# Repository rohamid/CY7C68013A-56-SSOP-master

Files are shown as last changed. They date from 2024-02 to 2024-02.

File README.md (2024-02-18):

# CY7C68013A 56 SSOP dev board

# Fix this:
* EEPROM connection's. I made a mistake for EERPOM address connection. Pin no.1 should be connected to EEPROM enable jumper.
* USB connector (if you gonna use usb C, don't do manual soldering. It doesn't really that strong, but if you gonna give it to PCBA I think it will gonna do it. Don't know why)
* Try black tactile button, it feel better

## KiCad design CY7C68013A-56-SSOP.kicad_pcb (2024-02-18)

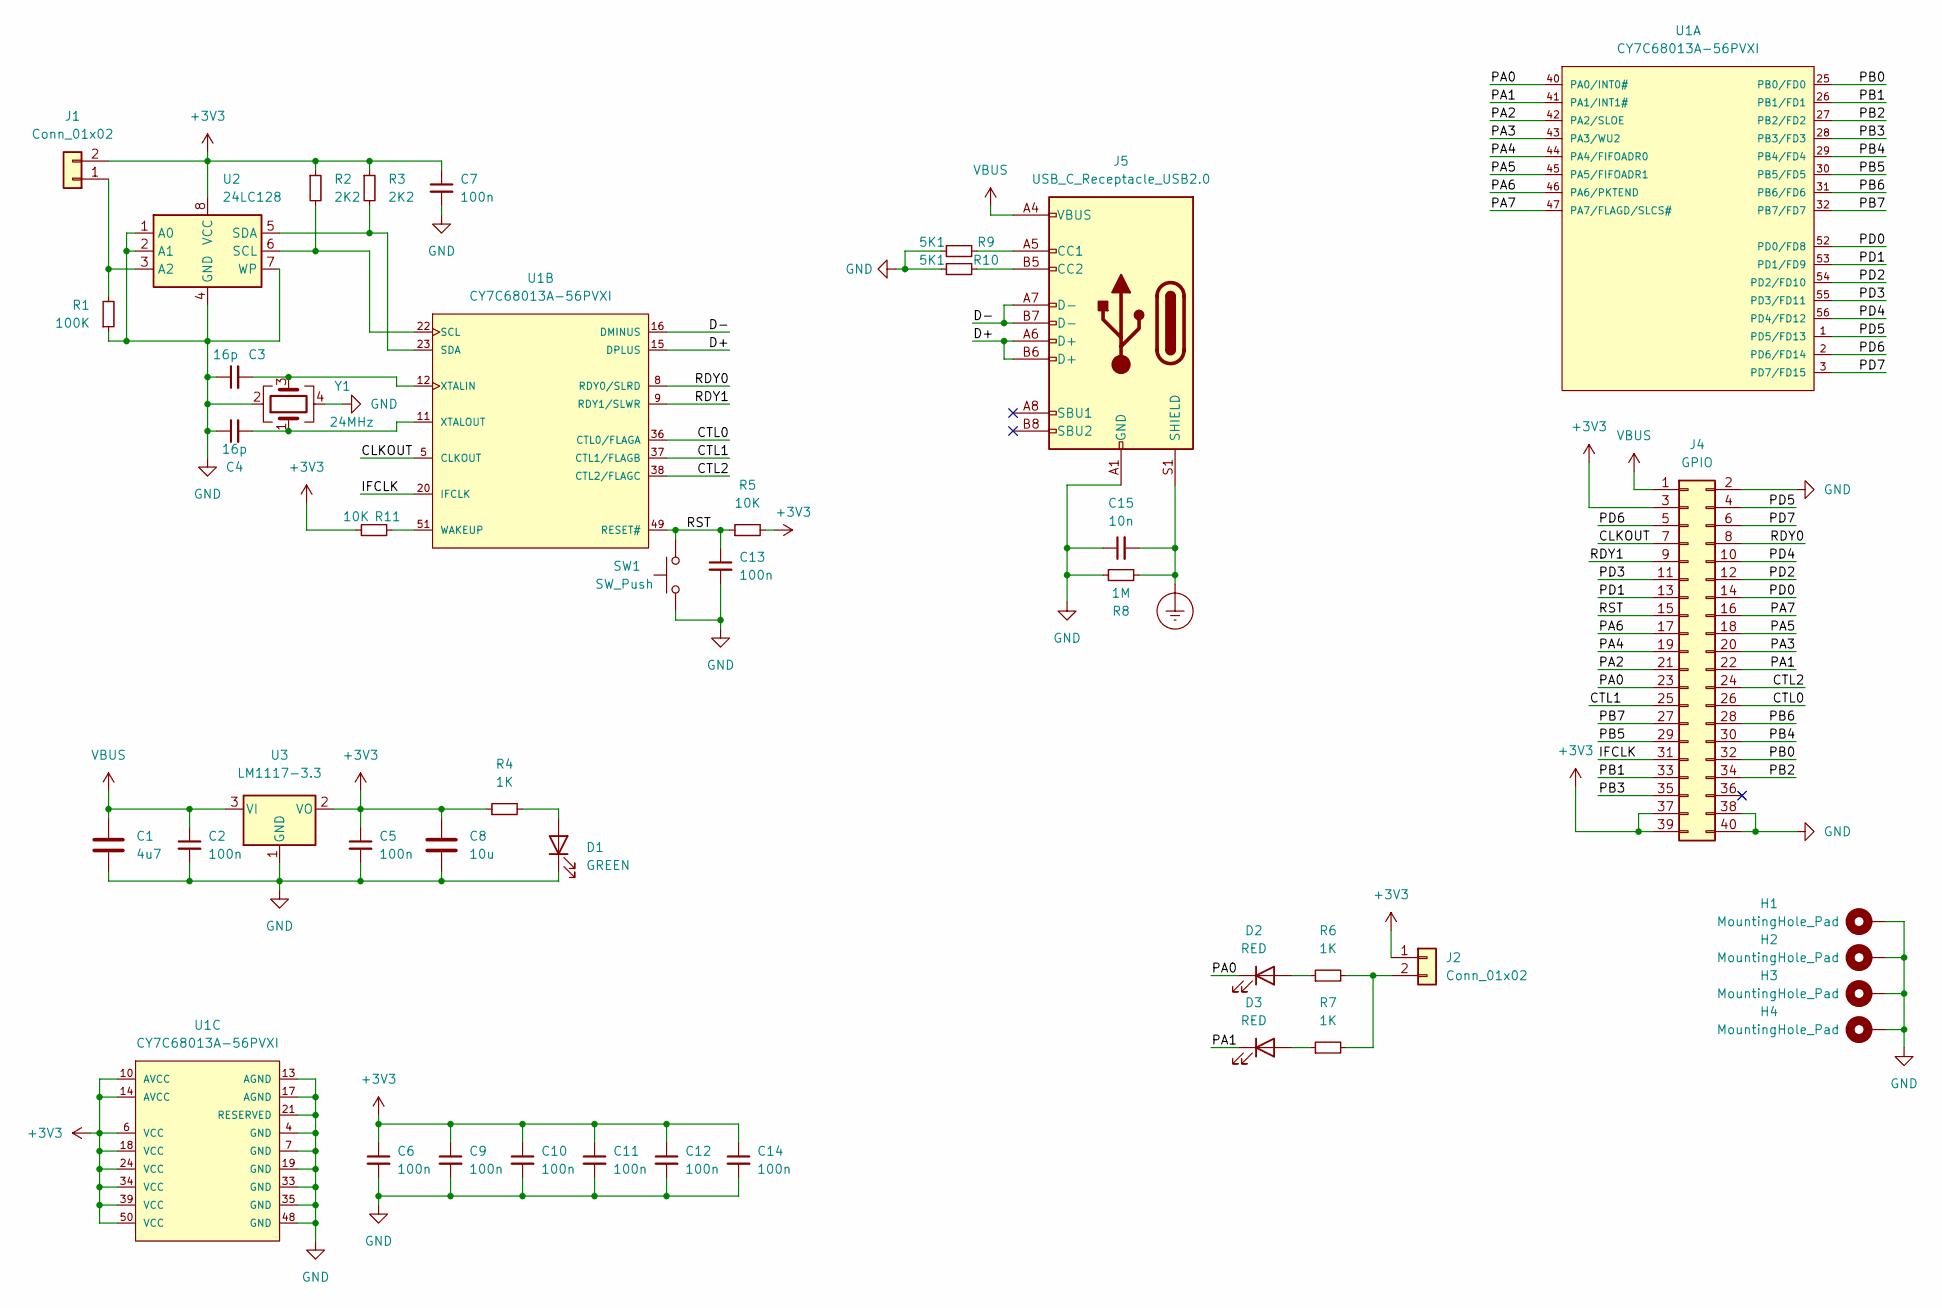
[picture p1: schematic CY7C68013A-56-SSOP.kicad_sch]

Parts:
C1: 4u7; C_0805_2012Metric; LCSC Part Number C1779
C2, C5, C6, C7, C9, C10, C11, C12, C13, C14: 100n; C_0402_1005Metric; LCSC Part Number C307331
C3, C4: 16p; C_0402_1005Metric; LCSC Part Number C1547
C8: 10u; C_0805_2012Metric; LCSC Part Number C15850
C15: 10n; C_0805_2012Metric; LCSC Part Number C106840
D1: GREEN; LED_0805_2012Metric; LCSC Part Number C34499
D2, D3: RED; LED_0805_2012Metric; LCSC Part Number C84256
H1, H2, H3, H4: MountingHole_Pad; MountingHole_3.2mm_M3_Pad_Via
J1, J2: Conn_01x02; PinHeader_1x02_P2.54mm_Vertical
J4: GPIO; PinHeader_2x20_P2.54mm_Horizontal
J5: USB_C_Receptacle_USB2.0; USB_C_Receptacle_G-Switch_GT-USB-7010ASV
R1: 100K; R_0402_1005Metric; LCSC Part Number C25741
R2, R3: 2K2; R_0402_1005Metric; LCSC Part Number C25879
R4, R6, R7: 1K; R_0402_1005Metric; LCSC Part Number C11702
R5: 10K; R_0402_1005Metric; LCSC Part Number C25744
R8: 1M; R_0402_1005Metric; LCSC Part Number C26083
R9, R10: 5K1; R_0402_1005Metric; LCSC Part Number C25744
R11: 10K; R_0402_1005Metric; LCSC Part Number C11702
SW1: SW_Push; SW_Push_1P1T_NO_CK_KMR2; LCSC Part Number C115360
U1: CY7C68013A-56PVXI; SSOP-56_7.5x18.5mm_P0.635mm; LCSC Part Number CY7C68013A-56PVXC
U2: 24LC128; SOIC-8_3.9x4.9mm_P1.27mm; LCSC Part Number C81195
U3: LM1117-3.3; SOT-223-3_TabPin2; LCSC Part Number C6186
Y1: 24MHz; Crystal_SMD_3225-4Pin_3.2x2.5mm; LCSC Part Number C2650460

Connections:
+3V3: C5.1, C6.1, C7.1, C8.1, C9.1, C10.1, C11.1, C12.1, C14.1, J1.2, J2.1, J4.3, J4.37, J4.39, R2.1, R3.1, R4.1, R5.2, R11.1, U1.6 (VCC), U1.10 (AVCC), U1.14 (AVCC), U1.18 (VCC), U1.24 (VCC), U1.34 (VCC), U1.39 (VCC), U1.50 (VCC), U2.8 (VCC), U3.2 (VO); also elsewhere on the board
/CLKOUT: J4.7, U1.5 (CLKOUT)
/CTL0: J4.26, U1.36 (CTL0/FLAGA)
/CTL1: J4.25, U1.37 (CTL1/FLAGB)
/CTL2: J4.24, U1.38 (CTL2/FLAGC)
/D+: J5.A6 (D+), J5.B6 (D+), U1.15 (DPLUS)
/D-: J5.A7 (D-), J5.B7 (D-), U1.16 (DMINUS)
/IFCLK: J4.31, U1.20 (IFCLK)
/PA0: D2.1 (K), J4.23, U1.40 (PA0/INT0#)
/PA1: D3.1 (K), J4.22, U1.41 (PA1/INT1#)
/PA2: J4.21, U1.42 (PA2/SLOE)
/PA3: J4.20, U1.43 (PA3/WU2)
/PA4: J4.19, U1.44 (PA4/FIFOADR0)
/PA5: J4.18, U1.45 (PA5/FIFOADR1)
/PA6: J4.17, U1.46 (PA6/PKTEND)
/PA7: J4.16, U1.47 (PA7/FLAGD/SLCS#)
/PB0: J4.32, U1.25 (PB0/FD0)
/PB1: J4.33, U1.26 (PB1/FD1)
/PB2: J4.34, U1.27 (PB2/FD2)
/PB3: J4.35, U1.28 (PB3/FD3)
/PB4: J4.30, U1.29 (PB4/FD4)
/PB5: J4.29, U1.30 (PB5/FD5)
/PB6: J4.28, U1.31 (PB6/FD6)
/PB7: J4.27, U1.32 (PB7/FD7)
/PD0: J4.14, U1.52 (PD0/FD8)
/PD1: J4.13, U1.53 (PD1/FD9)
/PD2: J4.12, U1.54 (PD2/FD10)
/PD3: J4.11, U1.55 (PD3/FD11)
/PD4: J4.10, U1.56 (PD4/FD12)
/PD5: J4.4, U1.1 (PD5/FD13)
/PD6: J4.5, U1.2 (PD6/FD14)
/PD7: J4.6, U1.3 (PD7/FD15)
/RDY0: J4.8, U1.8 (RDY0/SLRD)
/RDY1: J4.9, U1.9 (RDY1/SLWR)
/RST: C13.1, J4.15, R5.1, SW1.2, U1.49 (RESET#)
Earth_Protective: C15.2, J5.S1 (SHIELD), R8.2
GND: C1.2, C2.2, C3.1, C4.1, C5.2, C6.2, C7.2, C8.2, C9.2, C10.2, C11.2, C12.2, C13.2, C14.2, C15.1, D1.1 (K), H1.1, H2.1, H3.1, H4.1, J4.2, J4.38, J4.40, J5.A1 (GND), J5.A12 (GND), J5.B1 (GND), J5.B12 (GND), R1.1, R8.1, R9.1, R10.1, SW1.1, U1.4 (GND), U1.7 (GND), U1.13 (AGND), U1.17 (AGND), U1.19 (GND), U1.21 (RESERVED), U1.33 (GND), U1.35 (GND), U1.48 (GND), U2.1 (A0), U2.2 (A1), U2.4 (GND), U2.7 (WP), U3.1 (GND), Y1.2, Y1.4; also elsewhere on the board
unnamed: C3.2, U1.12 (XTALIN), Y1.3
unnamed: C4.2, U1.11 (XTALOUT), Y1.1
unnamed: D1.2 (A), R4.2
unnamed: D2.2 (A), R6.1
unnamed: D3.2 (A), R7.1
unnamed: J1.1, R1.2, U2.3 (A2)
unnamed: J2.2, R6.2, R7.2
unnamed: J5.A5 (CC1), R9.2
unnamed: J5.B5 (CC2), R10.2
unnamed: R2.2, U1.22 (SCL), U2.6 (SCL)
unnamed: R3.2, U1.23 (SDA), U2.5 (SDA)
unnamed: R11.2, U1.51 (WAKEUP)
VBUS: C1.1, C2.1, J4.1, J5.A4 (VBUS), J5.A9 (VBUS), J5.B4 (VBUS), J5.B9 (VBUS), U3.3 (VI); also elsewhere on the board

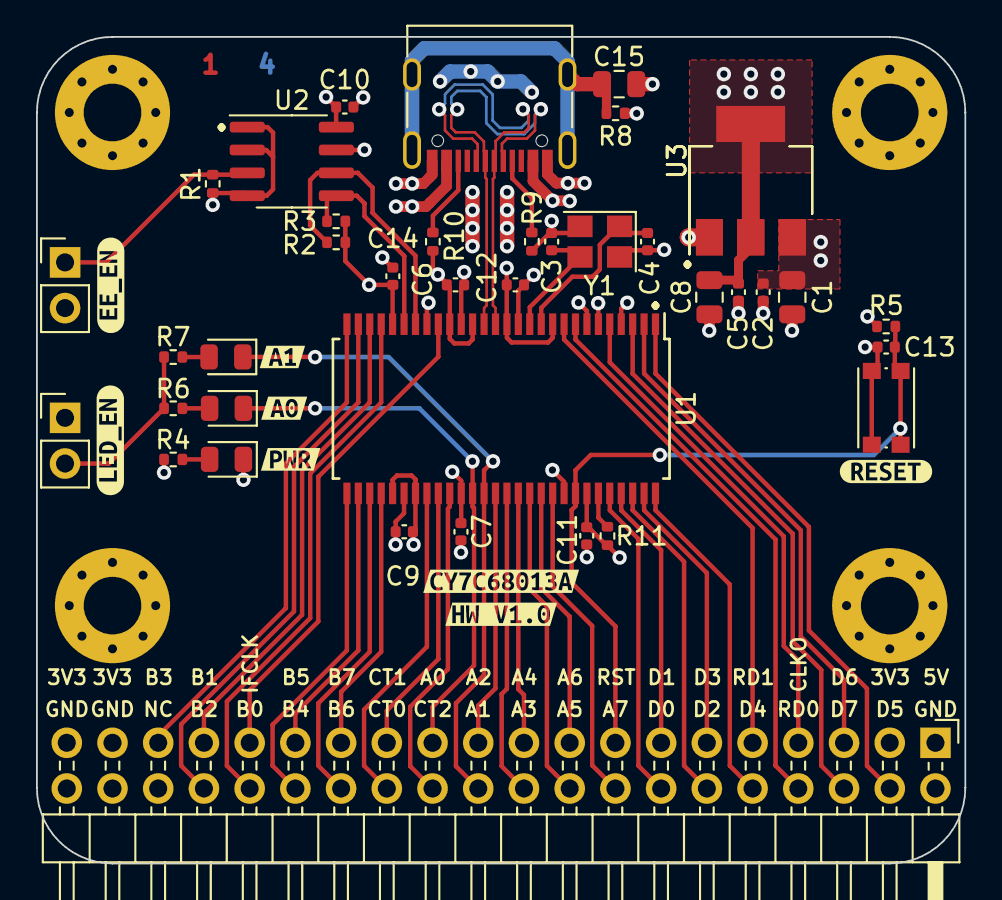
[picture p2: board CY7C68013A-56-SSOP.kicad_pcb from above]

Board: 4 copper layers, 51.6 x 45.9 mm, 51 parts (0 on the bottom side), 50 nets.

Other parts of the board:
U3#2: LM1117-3.3; SOT-223-3_TabPin2
kibuzzard-63EC9D7C: G***; kibuzzard-63EC9D7C
kibuzzard-63EC9D86: G***; kibuzzard-63EC9D86
kibuzzard-63F2CE48: G***; kibuzzard-63F2CE48
kibuzzard-63F2CE91: G***; kibuzzard-63F2CE91
kibuzzard-63F33066: G***; kibuzzard-63F33066
kibuzzard-63FDD9FB: G***; kibuzzard-63FDD9FB
kibuzzard-63FDDA02: G***; kibuzzard-63FDDA02
kibuzzard-63FDDA26: G***; kibuzzard-63FDDA26

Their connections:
+3V3: U3#2.2 (VO); also elsewhere on the board
GND: U3#2.1 (GND); also elsewhere on the board
VBUS: U3#2.3 (VI); also elsewhere on the board
